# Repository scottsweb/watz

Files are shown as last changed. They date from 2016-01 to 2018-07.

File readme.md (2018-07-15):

watz energy monitor

# watz

* Status: ✅ Active
* Contributors: [@scottsweb](http://twitter.com/scottsweb)
* Description: A WiFi smart meter / pulse counter built upon a Spark / Particle Core.
* Author: [Scott Evans](http://scott.ee)
* Author URI: [http://scott.ee](http://scott.ee)
* License: GNU General Public License v2.0
* License URI: [http://www.gnu.org/licenses/gpl-2.0.html](http://www.gnu.org/licenses/gpl-2.0.html)

## About

watz is a WiFi smart meter / pulse counter. It mounts to the LED on your electricity meter and measures the number of pulses in a given time period. This is used to generate real time power information. This data is periodically pushed to the Particle cloud and can be subscribed to via [server-sent](https://docs.particle.io/reference/firmware/core/#particle-publish-) events.

The events are:

* `watz` - pushed every 10 minutes, contains a `kW` reading and a pulse `count`
* `watzup` - pushed every time 1000 pulses are detected to allow tracking of the meter total
* `watzbatt` - pushed every 10 minutes and uses the official power shield to grab batter information

To log the data I am using the hosted [emoncms service](http://emoncms.org). I relay the data via
[Node-RED](http://nodered.org/) on a Raspberry Pi using the [Particle](http://flows.nodered.org/node/node-red-contrib-particle) and [emoncms](http://flows.nodered.org/node/node-red-node-emoncms) nodes:

watz node red

When the `kW` data arrives with emoncms you will need to multiply it by 1000 to get the current watts value. After a bit of tweaking your electricity dashboard should looks something like this:

watz data in a graph

Issues/Problems/Questions? [Open a GitHub issue](https://github.com/scottsweb/watz/issues). You can also contact me via [scott.ee](http://scott.ee) or [twitter (@scottsweb)](http://twitter.com/scottsweb).

## Hardware

* [Particle Photon](https://www.particle.io/)
* [Particle Power Shield](https://docs.particle.io/datasheets/particle-shields/#power-shield)
* [TSL251R-LF 3.3v Photodiode](http://uk.farnell.com/ams/tsl251r-lf/photodiode-sensor-l-volts/dp/1182347)
* A power source (I went for battery + solar as my meter is outside the house)

## Circuit

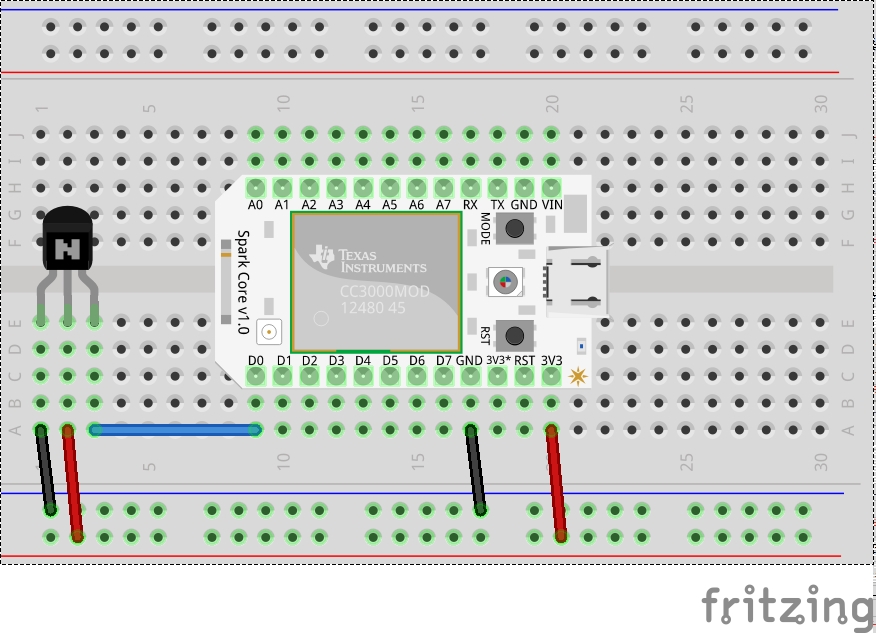
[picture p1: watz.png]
watz breadboard made with Fritzing


The included watz.fzz file can be opened in [Fritzing](http://fritzing.org/). Replace the transistor with the TSL251R-LF. Version 2.0 of the code the board requires the Photon and the TSL251R-LF to be attached to the WKP pin to bring the board out of deep sleep.

## Installation

Copy the contents of `watz.ino` into the [Particle Build IDE](https://build.particle.io/build/) and flash your Photon.

## Further Reading

* http://openenergymonitor.org/emon/buildingblocks/introduction-to-pulse-counting
* http://www.reuk.co.uk/Flashing-LED-on-Electricity-Meter.ht
* http://jeelabs.net/projects/cafe/wiki/Electricity_consumption_meter
* http://www.airsensor.co.uk/component/zoo/item/energy-monitor-mk2.html

## Changelog

### 2.0
* Upgraded to Photon board
* Added support for Power Shield
* Battery life monitoring 
* Deep sleeping to improve battery performance
* SEMI_AUTOMATTIC to have better control over cloud connection

### 1.0
* Initial release

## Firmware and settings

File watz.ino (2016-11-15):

#include "PowerShield/PowerShield.h"

// control when particle connects to cloud
SYSTEM_MODE(SEMI_AUTOMATIC);

// enable retianed memory
STARTUP(System.enableFeature(FEATURE_RETAINED_MEMORY));

// pins
int intled = D7;
int sensor = WKP;
int keepAwake = D0;

// general vars
char json[64];
char ip[24];

// timings
#define sleepTime 150 // 2.5 minutes before waking - during low power usage we force a check
#define updatePeriod 600 // update every 10 minutes

// function for interrupt
void pulse(void); 

// retained pulse vars
retained bool firstRun = true; // is this the first run?
retained float pulseCount = 0; // counts power pulses on sensor
retained unsigned long meterKW = 0; // counts towards a kwh 
retained int lastUpdate = 0; // set last update time to ensure a sync at start
retained int expectedWake = 0; // expected time to wake

// initiate power monitor
PowerShield batteryMonitor;

void setup() {
    
    // turn off core LED
    RGB.control(true);
    RGB.color(0, 0, 0);

    // set sensor as input
    pinMode(sensor, INPUT);
    
    // attach interrupt to sensor pin, when RISING
    attachInterrupt(sensor, pulse, RISING);
    
    // calculate if woken by time or wkp pin (this is wkp pin)
    if ((expectedWake - Time.now()) > 2) {

        // increment pulse count
        pulseCount += 1;
        
        // increment the kw total
        meterKW += 1;
    }
}

void loop() {
    
    if (firstRun) {
        
        // connect
        Particle.connect();

         // wait for wifi to connect (10 second timeout)
        if (waitFor(Particle.connected, 10000)) {
            
            // notify connection / boot
            RGB.color(0, 255, 0);

            // sync time with cloud on first run
            Particle.syncTime();
            
            // allow 5 seconds for sync of time
            delay(5000);
            
            // set a last update time to now
            lastUpdate = Time.now();
            
            // lights off
            RGB.color(0, 0, 0);
        }
        
        // run no more
        firstRun = false;
    }
    
    // publish once every 15 minutes(ish)
    if (Time.now() >= (lastUpdate + updatePeriod)) {
        publish();
    }
    
    // if pulse total equals 1000 then publish a meter count
    if (meterKW >= 1000) {
        publishTotal();
    }
    
    // deep sleep - wake up every 2.5 mins to keep data consistent if low power usage (no interrupts)
    // add a reed or hardward switch here for keeping awake - make flashing easier. Use D0
    // && (digitalRead(keepAwake) == HIGH)
    expectedWake = (Time.now() + sleepTime);
    System.sleep(SLEEP_MODE_DEEP, sleepTime);
}

void pulse() {
    
    // count pulses while booted
    // increment pulse count
    pulseCount += 1;
        
    // increment the kw total
    meterKW += 1;
}

void publish() {

    // connect
    Particle.connect();

    // wait for wifi to connect (10 second timeout)
    if (waitFor(Particle.connected, 10000)) {
        
        // starts the I2C bus
        batteryMonitor.begin(); 
        
        // sets up the fuel gauge
        batteryMonitor.quickStart();

        // sync time
        Particle.syncTime();
    
        // slow down or publish event fails
        delay(2000);
        
        // notify send
        // RGB.color(0, 0, 255);

        // prepare data
        // source: http://www.reuk.co.uk/Flashing-LED-on-Electricity-Meter.htm
        // 3600 seconds per hour
        float avgInterval = (Time.now() - lastUpdate) / pulseCount;  // average time between pulses since last update (seconds)
        float kw = 3600 / (avgInterval * 1000); // meter is 1000 imp/kWh
        
        // create json string
        sprintf(json,"{\"kw\": %.3f, \"count\": %.0f}", kw, pulseCount);

        // publish event to spark cloud
        bool success;
        success = Particle.publish("watz", json, 60, PRIVATE);
            
        // we need to check the data has arrived safely
        if (success) {
                
            // reset pulse count
            pulseCount = 0;
            
            // set last update time
            lastUpdate = Time.now();
        }
        
        // publish power details
        float cellVoltage = batteryMonitor.getVCell();
        float stateOfCharge = batteryMonitor.getSoC();
        sprintf(json,"{\"v\": %.2f, \"charge\": %.2f}", cellVoltage, stateOfCharge);
        Particle.publish("watzbatt", json, 60, PRIVATE);

        // slow down or publish event fails
        delay(2000);
    }
}

void publishTotal() {
    
    // connect
    Particle.connect();

    // wait for wifi to connect (10 second timeout)
    if (waitFor(Particle.connected, 10000)) {
        
        // sync time
        Particle.syncTime();
        
        // slow down or publish event fails
        delay(2000);

        // publish event to spark cloud
        bool success;
        success = Particle.publish("watzup", "{\"meter\": 1}", 60, PRIVATE);
            
        // we need to check the data has arrived safely
        if (success) {
    
            // reset total pulse count
            meterKW = 0;
        }

        // slow down or publish event fails
        delay(2000);
    }
}

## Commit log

2016-01-03 Update fritzing file
    [watz.fzz]
2016-11-15 Version 2.0
    Updated to support the Photon board along with the official power shield. The Photon should allow for better energy performance as data is easily stored in deep sleep now.
